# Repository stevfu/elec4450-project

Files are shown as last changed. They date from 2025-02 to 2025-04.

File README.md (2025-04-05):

# Custom Buck Converter 
My group designed a unidirectional buck converter with an active low-pass filter and control using a C2000 microcontroller.

The following specifications for this converter are: 

$$
V_i = 36\text{V} - 50\text{V}
$$

$$
V_o = 30\text{V}
$$

$$
f_{sw} = 10\text{kHz}
$$

$$
\Delta I_L = 0.3 I_L
$$

$$
\Delta V_o = 0.005 V_o
$$

The layout, schematic and PCB design of the buck converter was done in KiCAD. 

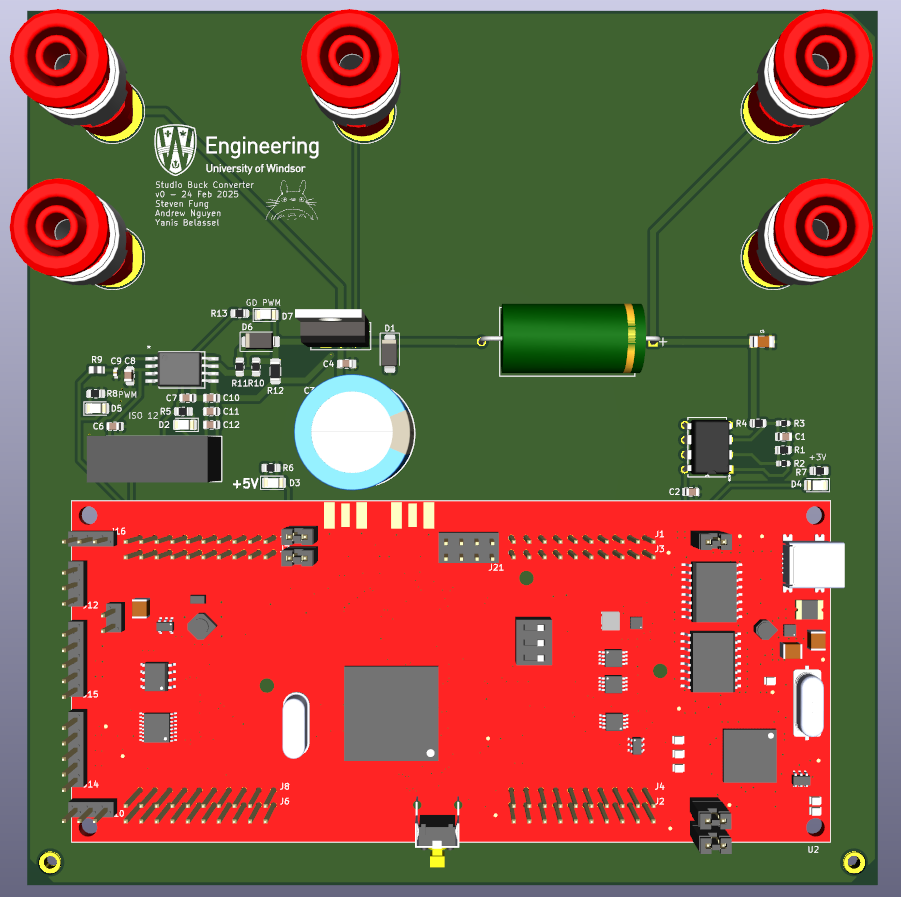
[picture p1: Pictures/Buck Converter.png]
Buck Converter


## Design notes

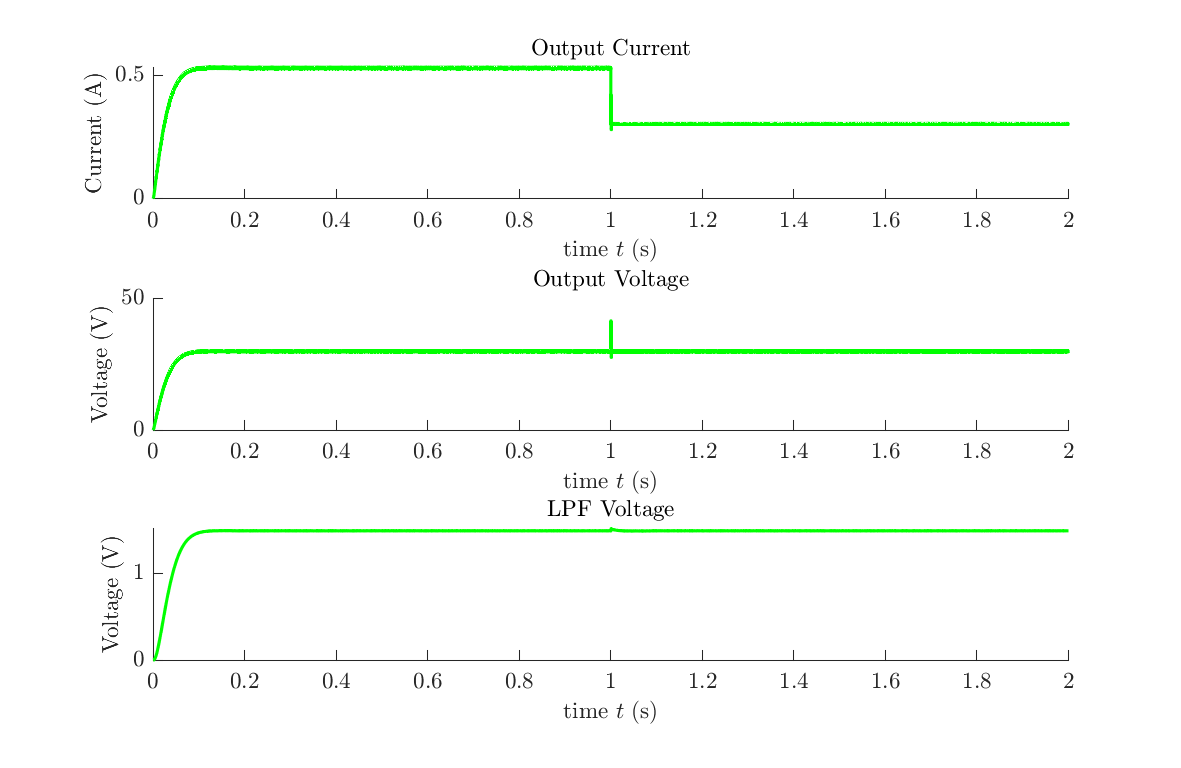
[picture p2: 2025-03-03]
Pictures/Power Output.png

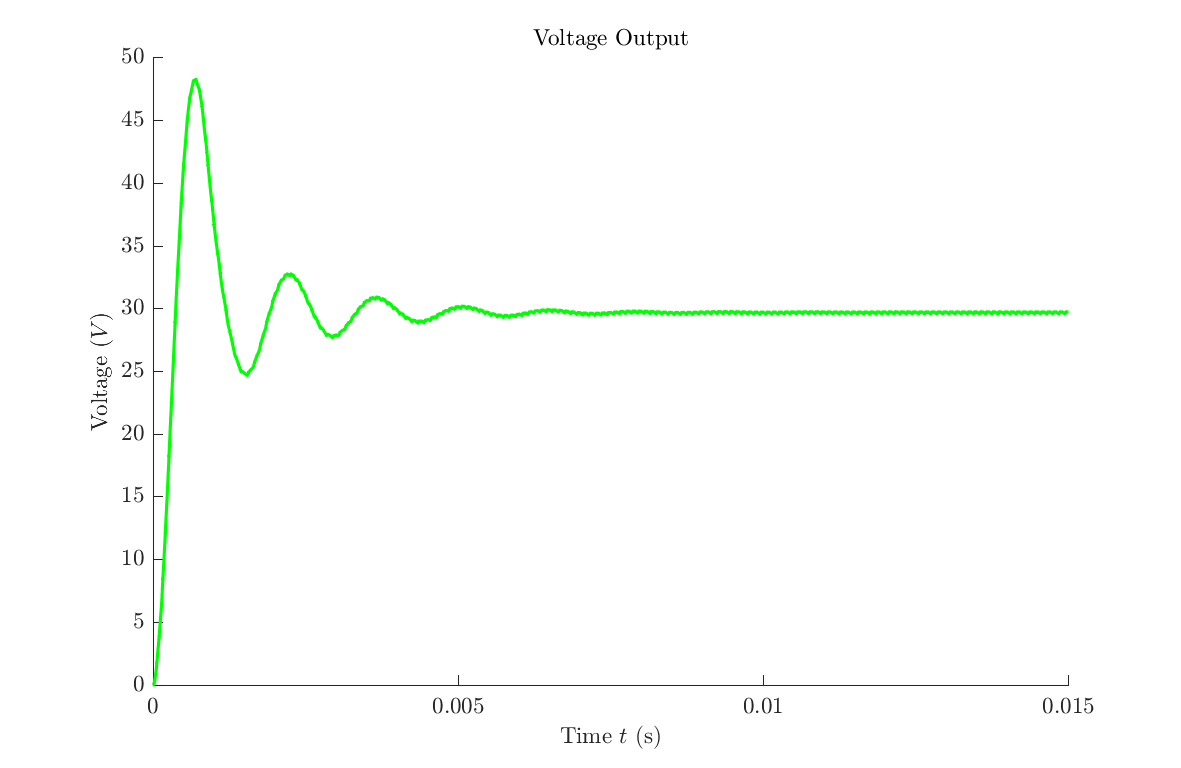
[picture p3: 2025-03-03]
Pictures/Voltage Output.png

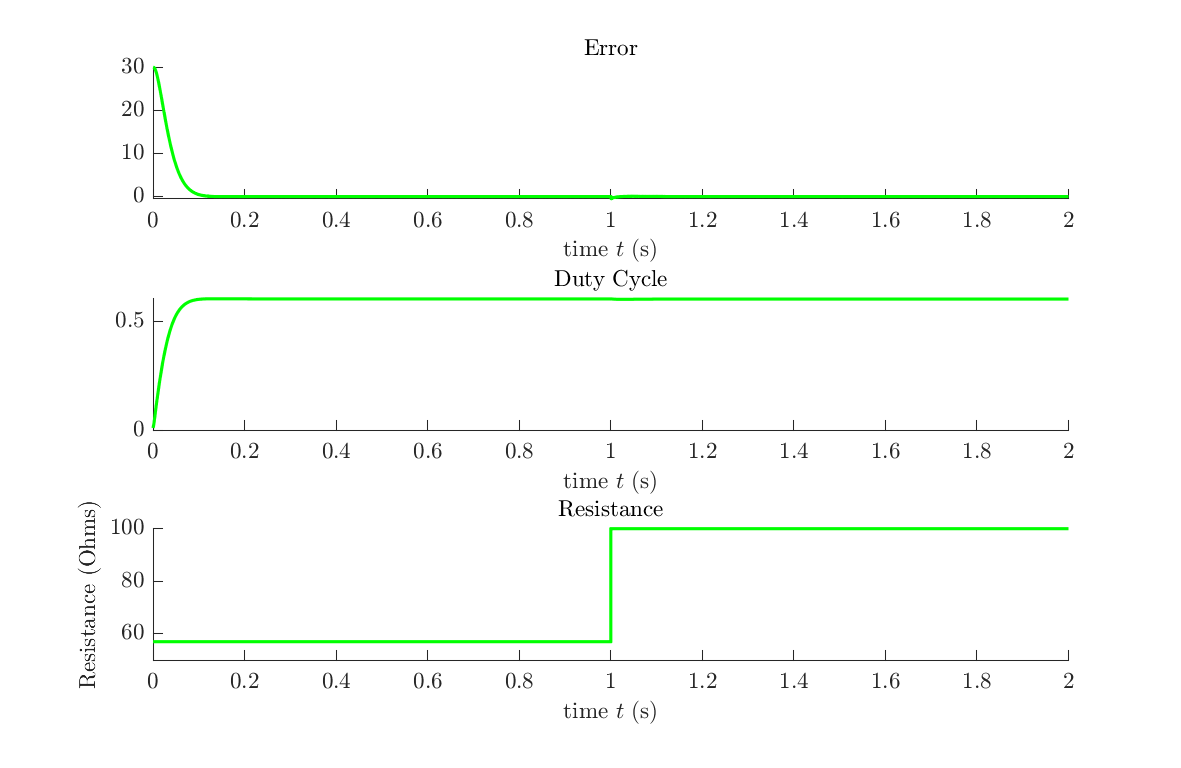
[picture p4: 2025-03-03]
Pictures/Controller Output.png

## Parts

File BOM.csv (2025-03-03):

Reference | Value | Qty | Part Number
C5 | 4.7 µF | 1 | GRM31CC72A475KE11L
L1 | 33mH | 1 | 5900-333-RC
U1 | LM358AP | 1 | LM358AP
U2 | LAUNCHXL-F28379D | 1 | LAUNCHXL-F28379D
U3 | UCC5304DWVR | 1 | UCC5304DWVR
D1 | SS310 | 1 | SS310
Q1 | IRF540NL | 1 | IRF540N
D6 | US2AA | 1 | US2AA
C9 | 33p | 1 | 600F330FT250XT
D2,D3,D4,D5,D7 | IR26-21C_L110_TR8 | 5 | IR26-21C_L110_TR8
C11 | 220n | 1 | C0805C224K5RACTU
C12 | 10u | 1 | GRM21BR61E106KA73L
C3 | 470u | 1 | 100ZLH470MEFC16X31.5
J1,J2,J3,J4,J5 | Conn_01x01_Pin | 5 | BU-P72930
R9 | 51 | 1 | RC0805FR-0751RL
R1,R4 | 10k | 2 | RMCF0805FT10K0
R2,R3 | 500 | 2 | RT0603BRC07500RL
R5,R6,R7,R8,R13 | 3.3k | 5 | ERU-P06F3301V
R10 | 7 | 1 | CRCW08057R15FKEA
R11 | 12 | 1 | RC0805FR-0712RL
R12 | 50 | 1 | RCP1206W50R0JTP
C2,C6,C7,C8 | 1u | 4 | TMCP1E105MTRF
U4 | TMV 0512SHI | 1 | TMV 0512SHI
C1 | 22u | 1 | C2012X5R1V226M125AC
C4 | 1u | 1 | GRM21BC72A105KE01L
C10 | 10u | 1 | F951C106MPAAQ2
Heatsink |  | 1 | 577202B00000G
Standoffs |  | 4 | 971100244
MCU Connectors |  | 4 | 61202021621

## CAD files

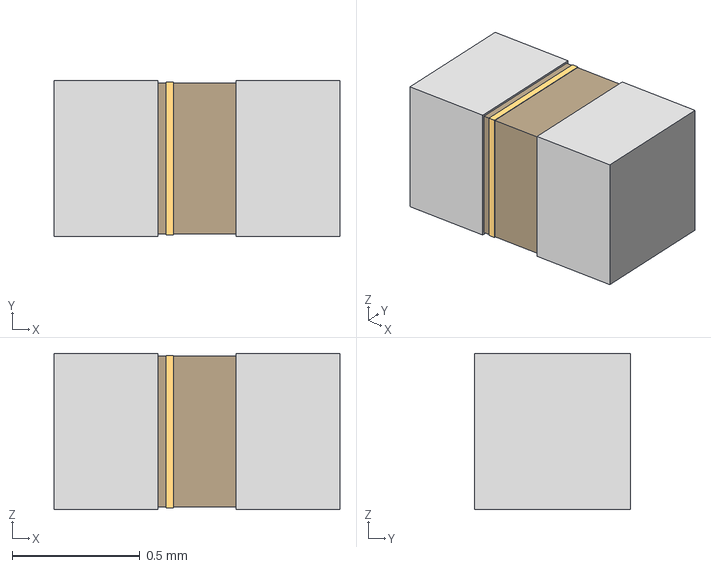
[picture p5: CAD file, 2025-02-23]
BuckConverter/600F330FT250XT/CAP_600F0R1AT250T_ATC.step
1.12 x 0.61 x 0.61 mm

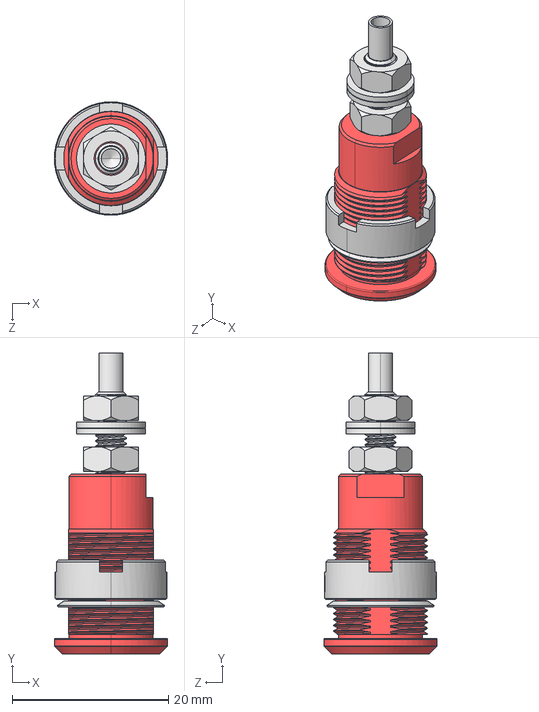
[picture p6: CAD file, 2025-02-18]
BuckConverter/Banana Socket 3D Model/3D/49.7043-22.stp
14.5 x 38.5 x 14.5 mm

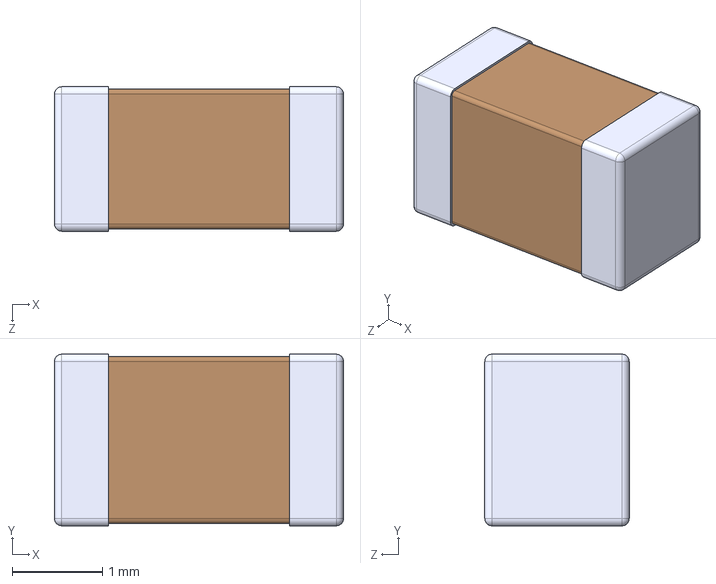
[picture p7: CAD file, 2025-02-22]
BuckConverter/GRM31CC72A475KE11L/GRM31CC72A475KE11L.step
3.20 x 1.90 x 1.60 mm

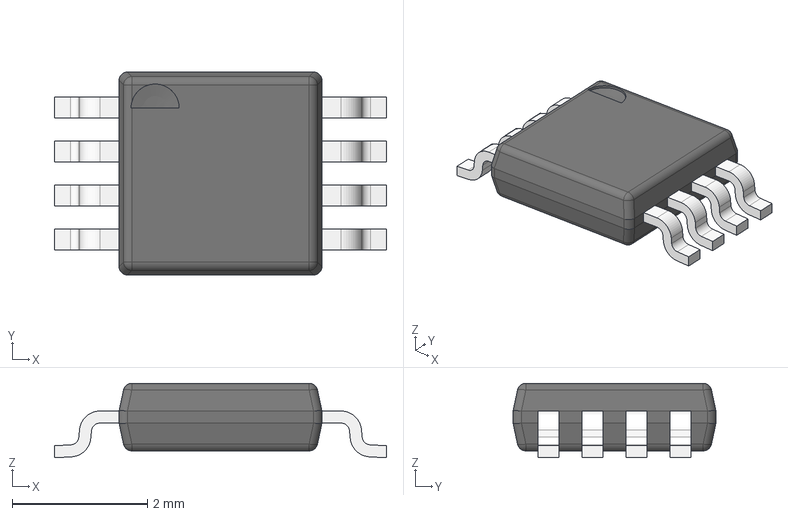
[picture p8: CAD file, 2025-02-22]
BuckConverter/LM358DGKR/DGK0008A.stp
4.90 x 3.00 x 1.10 mm
BODY_MUA08A
LEAD_MUA08A x 8

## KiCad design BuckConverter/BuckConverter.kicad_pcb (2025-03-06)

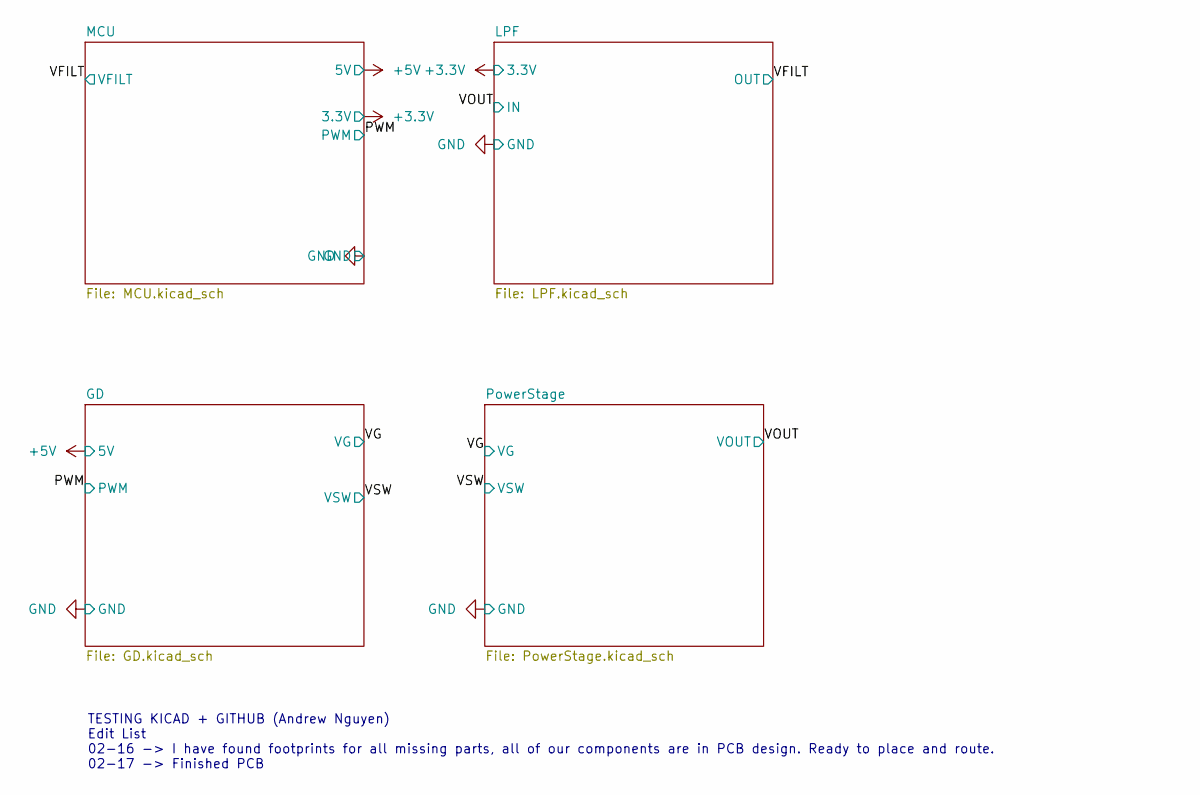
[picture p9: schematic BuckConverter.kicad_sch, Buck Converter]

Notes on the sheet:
TESTING KICAD + GITHUB (Andrew Nguyen) Edit List 02-16 -> I have found footprints for all missing parts, all of our components are in PCB design. Ready to place and route. 02-17 -> Finished PCB

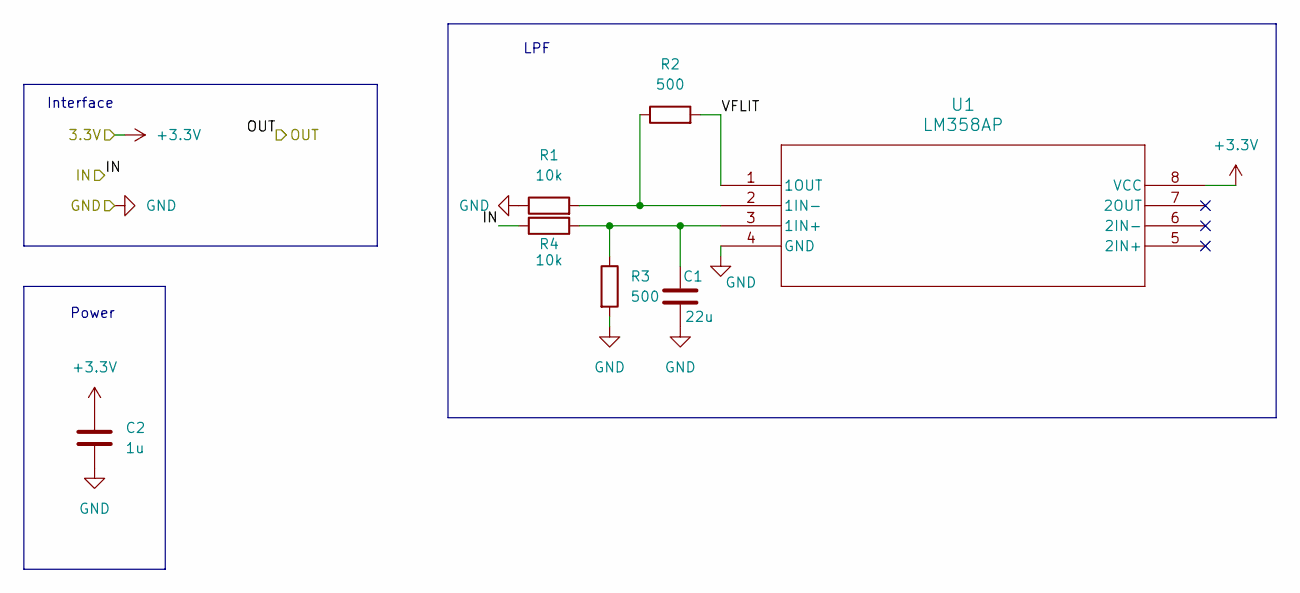
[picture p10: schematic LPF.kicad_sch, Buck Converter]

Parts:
C1: 22u; C_0805_2012Metric; Part Number C2012X5R1V226M125AC
C2: 1u; C_0805_2012Metric; Part Number TMCP1E105MTRF
R1, R4: 10k; R_0805_2012Metric; Part Number RMCF0805FT10K0
R2, R3: 500; R_0603_1608Metric; Part Number RT0603BRC07500RL
U1: LM358AP; P8; Part Number LM358AP

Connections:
+3.3V: C2.1, U1.8 (VCC); also elsewhere on the board
/LPF/VFLIT: R2.2, U1.1 (1OUT)
/VOUT: R4.2; also elsewhere on the board
GND: C1.2, C2.2, R1.1, R3.2, U1.4 (GND); also elsewhere on the board
unnamed: C1.1, R3.1, R4.1, U1.3 (1IN+)
unnamed: R1.2, R2.1, U1.2 (1IN-)

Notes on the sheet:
Power
Interface
LPF

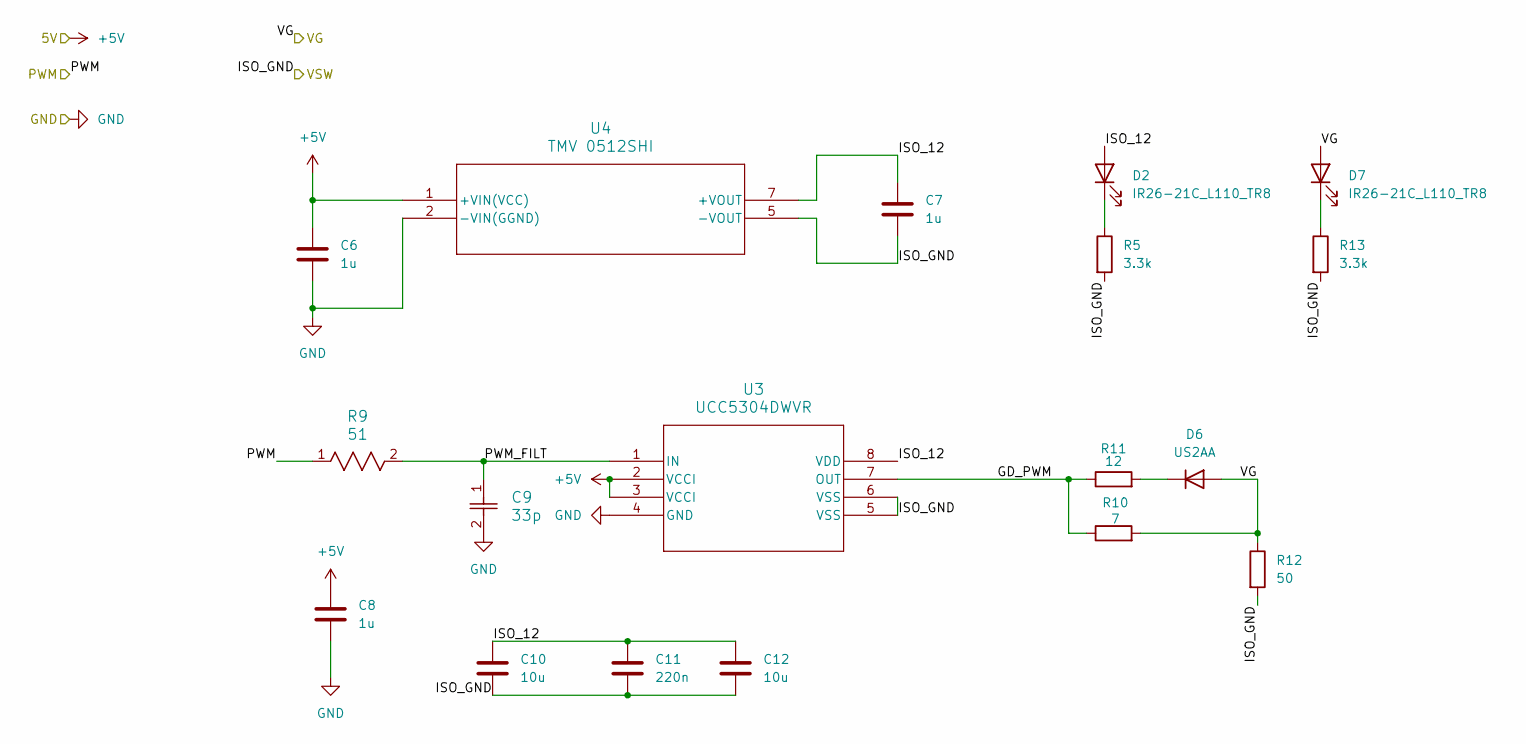
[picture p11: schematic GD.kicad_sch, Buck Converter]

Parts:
C6, C7: 1u; C_0805_2012Metric; Part Number TMCP1E105MTRF
C8: 1u; C_0805_2012Metric_Pad1.18x1.45mm_HandSolder; Part Number TMCP1E105MTRF
C9: 33p; CAP_600F0R1AT250T_ATC; Part Number 600F330FT250XT
C10: 10u; C_0805_2012Metric; Part Number F951C106MPAAQ2
C11: 220n; C_0805_2012Metric; Part Number C0805C224K5RACTU
C12: 10u; C_0805_2012Metric; Part Number GRM21BR61E106KA73L
D2, D7: IR26-21C_L110_TR8; LED_1206_3216Metric; Part Number IR26-21C_L110_TR8
D6: US2AA; D_SMA; Part Number US2AA
R5, R13: 3.3k; R_0805_2012Metric_Pad1.20x1.40mm_HandSolder; Part Number ERU-P06F3301V
R9: 51; RC0805N_YAG; Part Number RC0805FR-0751RL
R10: 7; R_0805_2012Metric_Pad1.20x1.40mm_HandSolder; Part Number CRCW08057R15FKEA
R11: 12; R_0805_2012Metric_Pad1.20x1.40mm_HandSolder; Part Number RC0805FR-0712RL
R12: 50; R_1206_3216Metric_Pad1.30x1.75mm_HandSolder; Part Number RCP1206W50R0JTP
U3: UCC5304DWVR; SOIC8_DWV_TEX; Part Number UCC5304DWVR
U4: TMV 0512SHI; TMV-HI_SINGLE_TRP; Part Number TMV 0512SHI

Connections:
+5V: C6.1, C8.1, U3.2 (VCCI), U3.3 (VCCI), U4.1 (+VIN(VCC)); also elsewhere on the board
/GD/GD_PWM: R10.1, R11.1, U3.7 (OUT)
/GD/ISO_12: C7.1, C10.1, C11.1, C12.1, D2.2 (A), U3.8 (VDD), U4.7 (+VOUT)
/GD/PWM_FILT: C9.1, R9.2, U3.1 (IN)
/PWM: R9.1; also elsewhere on the board
/VG: D6.2 (A), D7.2 (A), R10.2, R12.1; also elsewhere on the board
/VSW: C7.2, C10.2, C11.2, C12.2, R5.2, R12.2, R13.2, U3.5 (VSS), U3.6 (VSS), U4.5 (-VOUT); also elsewhere on the board
GND: C6.2, C8.2, C9.2, U3.4 (GND), U4.2 (-VIN(GGND)); also elsewhere on the board
unnamed: D2.1 (K), R5.1
unnamed: D6.1 (K), R11.2
unnamed: D7.1 (K), R13.1

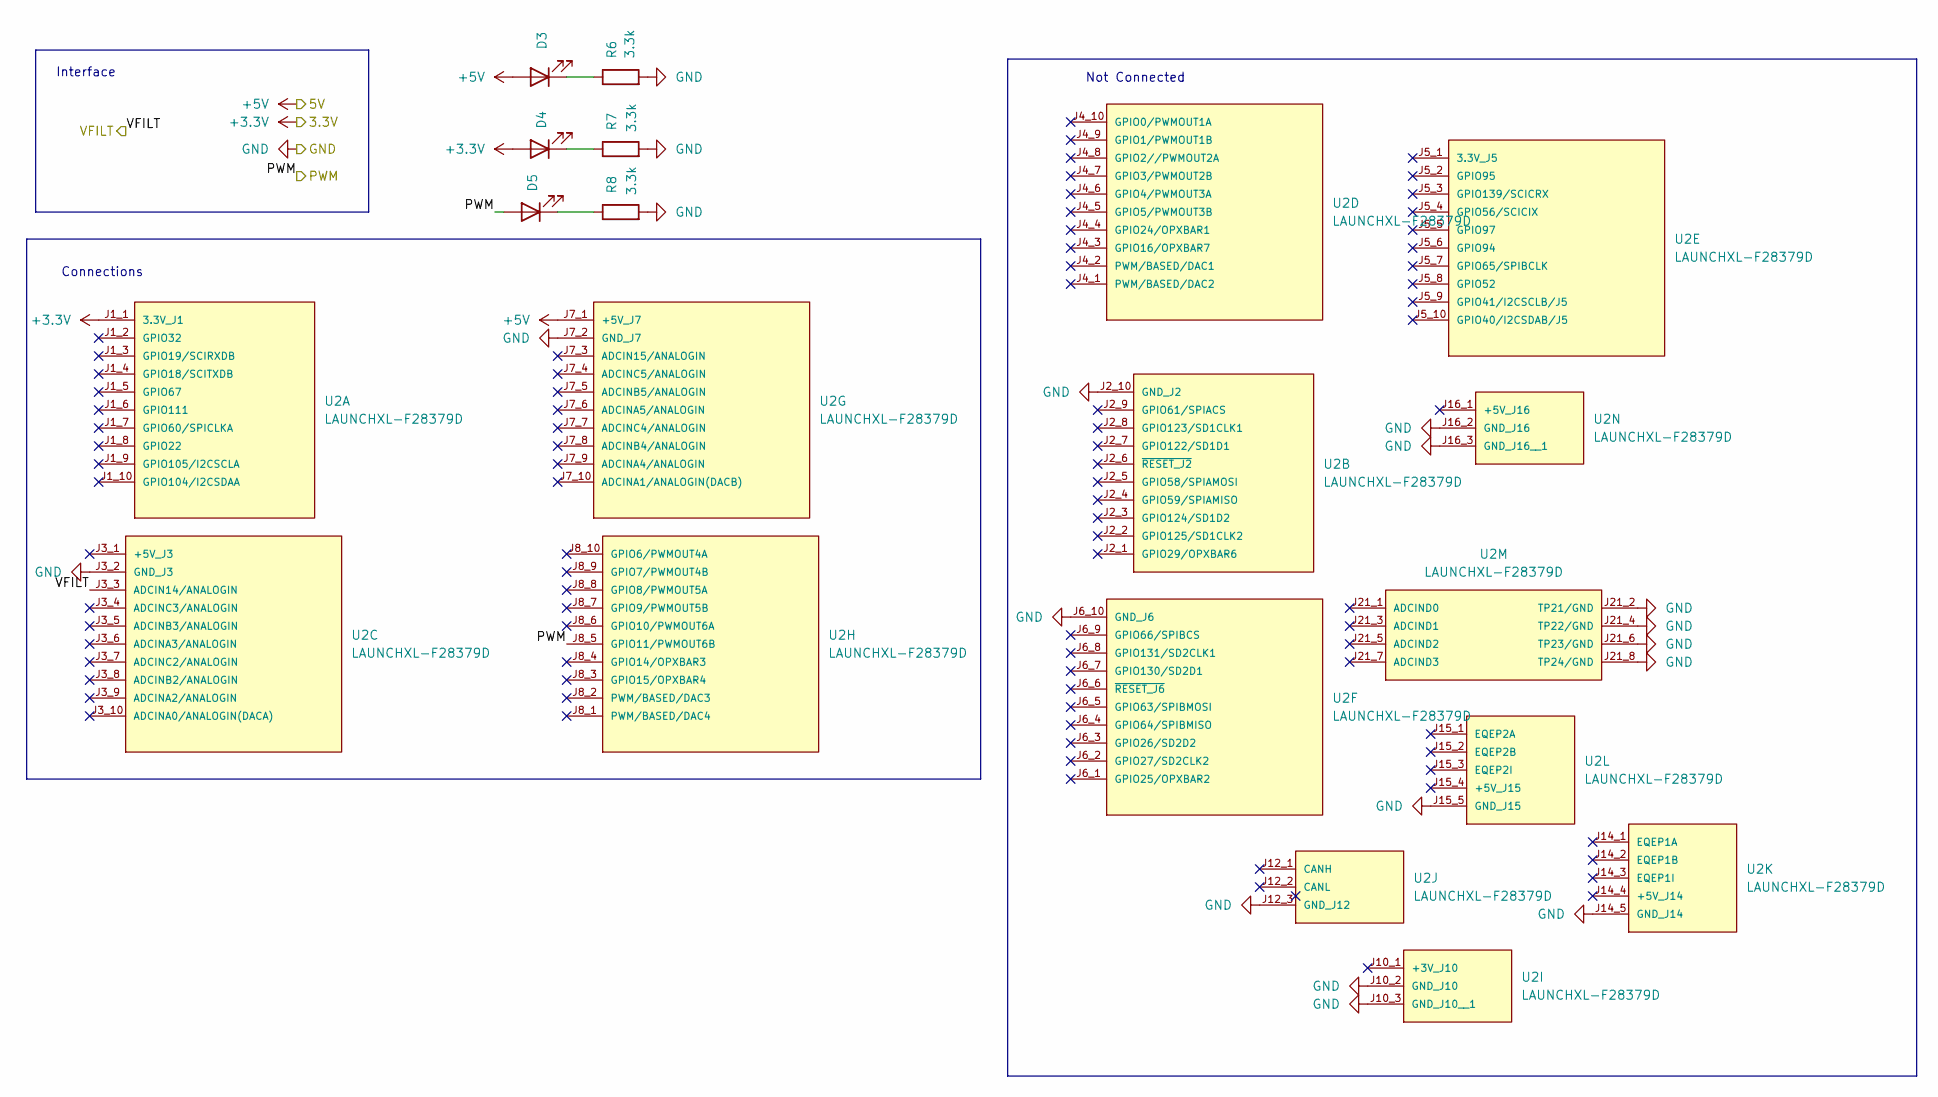
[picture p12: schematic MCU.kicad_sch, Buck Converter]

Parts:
D3, D4, D5: IR26-21C_L110_TR8; LED_1206_3216Metric; Part Number IR26-21C_L110_TR8
R6, R7, R8: 3.3k; R_0805_2012Metric_Pad1.20x1.40mm_HandSolder; Part Number ERU-P06F3301V
U2: LAUNCHXL-F28379D; MOD_LAUNCHXL-F28379D; PARTREV 2.0

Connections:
+3.3V: D4.2 (A), U2.J1_1 (3.3V_J1); also elsewhere on the board
+5V: D3.2 (A), U2.J7_1 (+5V_J7); also elsewhere on the board
/PWM: D5.2 (A), U2.J8_5 (GPIO11/PWMOUT6B); also elsewhere on the board
/VFILT: U2.J3_3 (ADCIN14/ANALOGIN)
GND: R6.2, R7.2, R8.2, U2.J2_10 (GND_J2), U2.J3_2 (GND_J3), U2.J6_10 (GND_J6), U2.J7_2 (GND_J7), U2.J10_2 (GND_J10), U2.J10_3 (GND_J10__1), U2.J12_3 (GND_J12), U2.J14_5 (GND_J14), U2.J15_5 (GND_J15), U2.J16_2 (GND_J16), U2.J16_3 (GND_J16__1), U2.J21_2 (TP21/GND), U2.J21_4 (TP22/GND), U2.J21_6 (TP23/GND), U2.J21_8 (TP24/GND); also elsewhere on the board
unnamed: D3.1 (K), R6.1
unnamed: D4.1 (K), R7.1
unnamed: D5.1 (K), R8.1

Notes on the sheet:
Not Connected
Connections
Interface

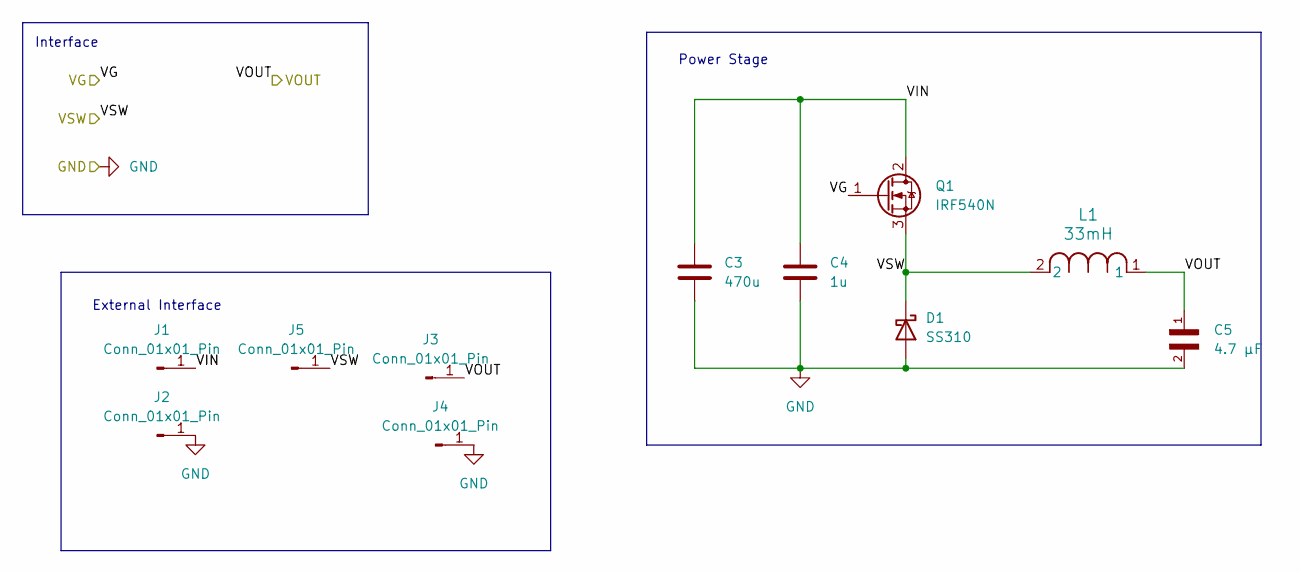
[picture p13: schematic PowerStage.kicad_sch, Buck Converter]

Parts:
C3: 470u; CP_Radial_D18.0mm_P7.50mm; Part Number 100ZLH470MEFC16X31.5
C4: 1u; C_0805_2012Metric_Pad1.18x1.45mm_HandSolder; Part Number GRM21BC72A105KE01L
C5: 4.7 µF; CAPC3216X190N; Part Number GRM31CC72A475KE11L
D1: SS310; D_SMA; Part Number SS310
J1, J2, J3, J4, J5: Conn_01x01_Pin; Banana_Jack_1Pin; Part Number BU-P72930
L1: 33mH; IND_BOURNS_5900; Part Number 5900-333-RC
Q1: IRF540N; TO-220-3_Vertical; Part Number IRF540N

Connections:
/PowerStage/VIN: C3.1, C4.1, J1.1, Q1.2 (D)
/VG: Q1.1 (G); also elsewhere on the board
/VOUT: C5.1, J3.1, L1.1; also elsewhere on the board
/VSW: D1.1 (K), J5.1, L1.2, Q1.3 (S); also elsewhere on the board
GND: C3.2, C4.2, C5.2, D1.2 (A), J2.1, J4.1; also elsewhere on the board

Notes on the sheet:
External Interface
Power Stage
Interface

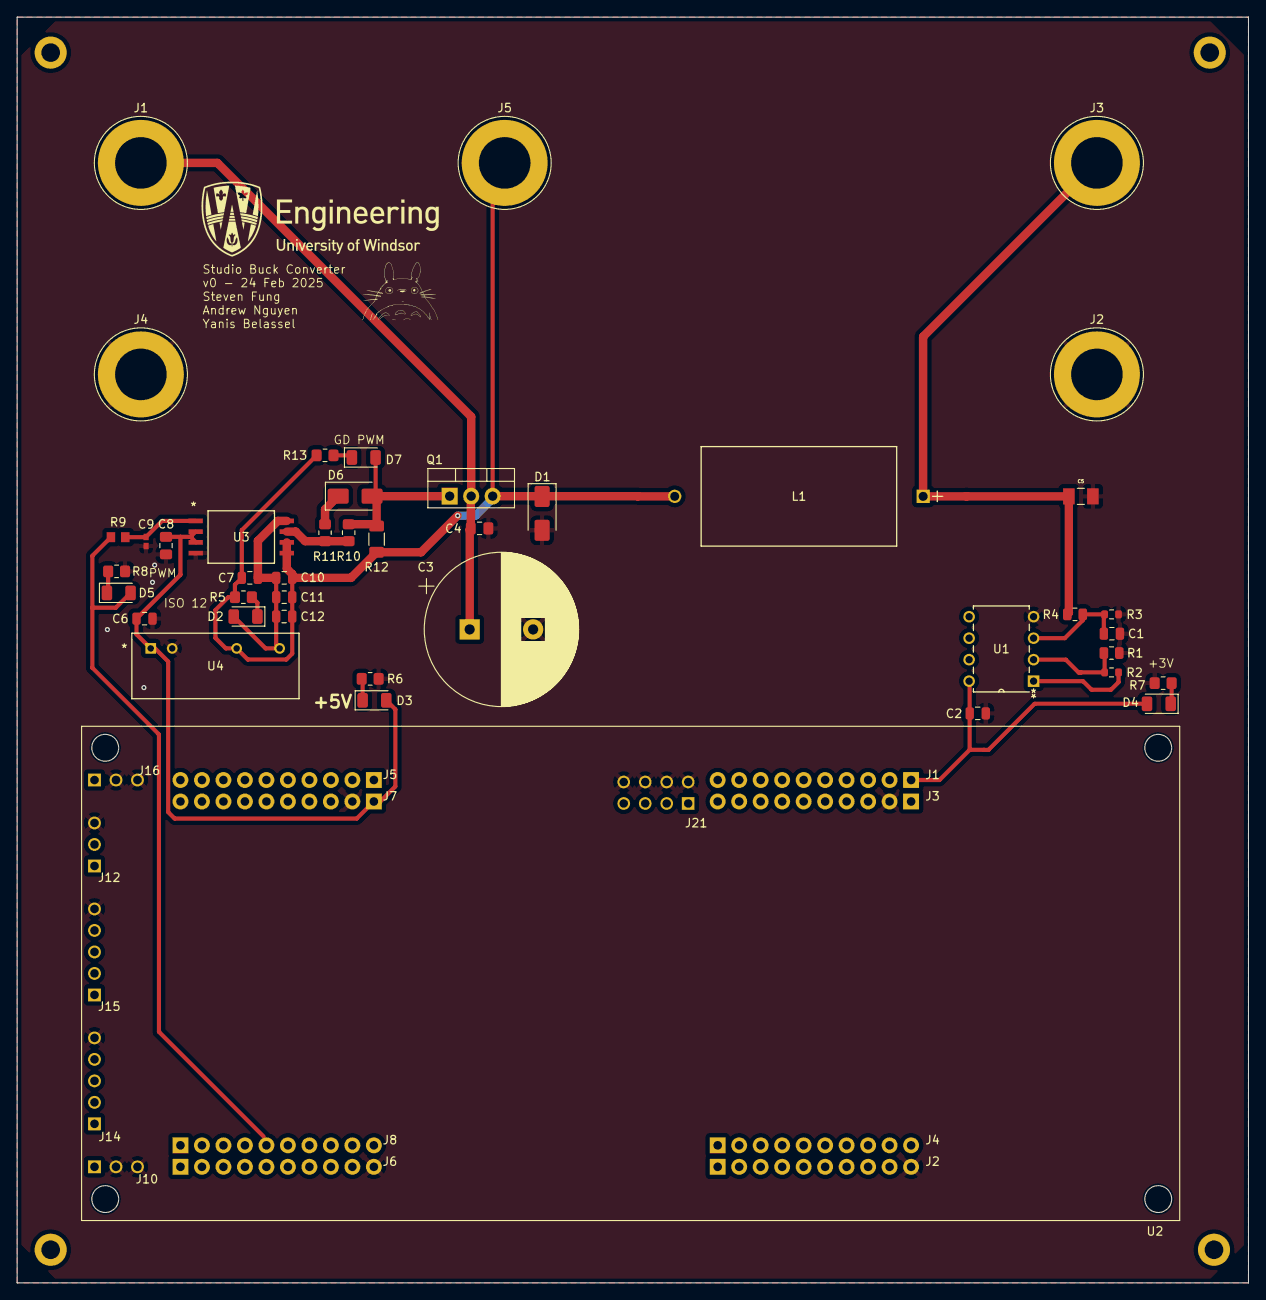
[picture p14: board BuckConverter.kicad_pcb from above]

Board: 2 copper layers, 145.5 x 149.6 mm, 43 parts (0 on the bottom side), 20 nets.

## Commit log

2025-02-02 updated buckConverter.slx
2025-02-02 Initial commit(Just schm so far)
    [BuckConverter.kicad_pcb, BuckConverter.kicad_sch, GD.kicad_sch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]
2025-02-16 Add all footprints
    [BuckConverter.kicad_pcb, BuckConverter.kicad_sch, GD.kicad_sch]
2025-02-18 PCB Completed
    [49.7043-22.stp, BuckConverter.kicad_pcb, BuckConverter.kicad_sch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]
2025-02-20 basic simulink model done
    [BuckConverter.kicad_pcb]
2025-02-22 added sample picture
2025-02-22 LPF updates
    [BuckConverter.kicad_pcb, LPF.kicad_sch]
2025-02-22 pcb name printed
    [BuckConverter.kicad_pcb]
2025-02-22 PCB updated LC footprints
    [BuckConverter.kicad_pcb, DGK0008A.stp, GD.kicad_sch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]
2025-02-23 PCB Final Draft
    [BuckConverter.kicad_pcb, CAP_600F0R1AT250T_ATC.step, GD.kicad_sch]
2025-02-24 updated BOM
    [GD.kicad_sch, MCU.kicad_sch, PowerStage.kicad_sch]
2025-02-25 Added subtitle and y-axis labelling
2025-02-25 added BOM cvs
    [BuckConverter.csv, GD.kicad_sch]
2025-02-27 Added BOM to main tree
    [BuckConverterBOM.csv]
2025-03-03 Update PCB and BOM
    [BOM.csv, BuckConverter.csv, BuckConverter.kicad_pcb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]
2025-03-06 added picture of pcb
    [BuckConverter-B_Cu.gbr, BuckConverter-B_Mask.gbr, BuckConverter-B_Paste.gbr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]
